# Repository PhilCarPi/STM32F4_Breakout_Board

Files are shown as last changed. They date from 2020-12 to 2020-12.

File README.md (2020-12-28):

# STM32F4_Breakout_Board
4 layer PCB that serves as a breakout board to an STM32F405 chip with an additional IMU chip just for fun. The breakout is for serial ports SPI, USART, I2C, and SWD.

## Front
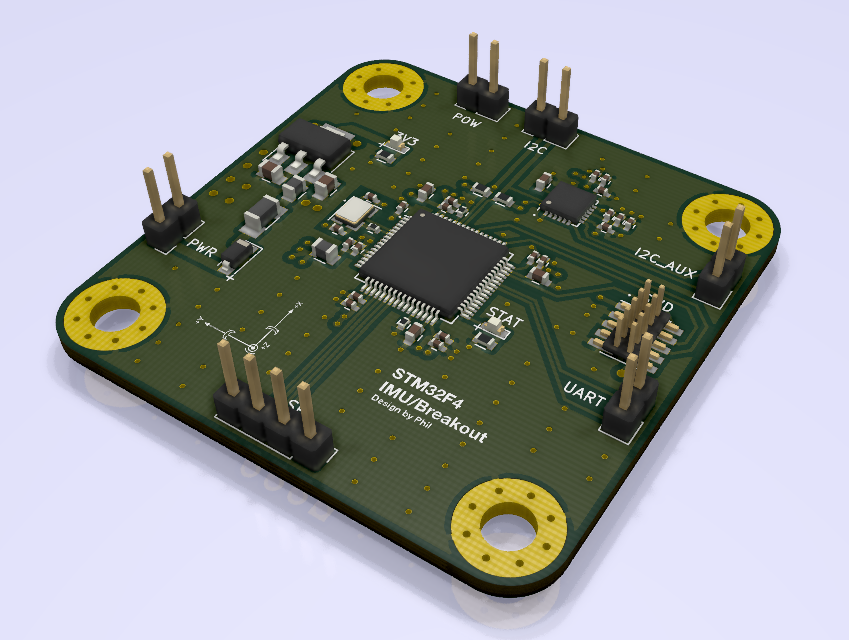
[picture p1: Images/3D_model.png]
3D Model of the board

## Back
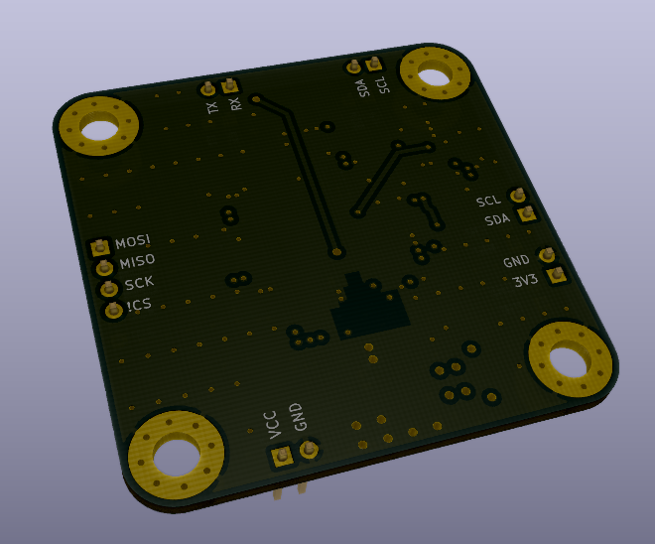
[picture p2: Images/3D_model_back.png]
3D Model of the board


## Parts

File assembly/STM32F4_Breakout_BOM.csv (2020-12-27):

Designator | Quantity | Value | Footprint | LCSC Part #
C1, C2, | 2 | 10uF | 0805 | C15850
C3, | 1 | 10uF | 0603 | C19702
C14, C13, | 2 | 12pF | 0402 | C1547
C15, C4, C5, C6, C7, C8, C9, C10, C11, C12, | 10 | 100nF | 0402 | C1525
C16, | 1 | 10nF | 0402 | C15195
C17, C18, | 2 | 2.2uF | 0603 | C23630
D1, | 1 | B5819W | SOD-123 | C8598
D2, | 1 | Green | 0603 | C72043
D3, | 1 | Blue | 0603 | C72041
F1, | 1 | 500mA | 1206 | C163133
FB1, FB2, | 2 | 100 @ 100Mhz | 0805 | C1015
HSE1, | 1 | 16MHz | SMD-3225_4P | C13738
R2, | 1 | 220 | 0402 | C25091
R5, R6, | 2 | 10k | 0402 | C25744
R7, R1, R4, R3, | 4 | 2k2 | 0603 | C4190
U1, | 1 | AMS1117-3.3 | SOT-223 | C6186
U2, | 1 | STM32F405RGT6 | LQFP-64_10.0x10.0x0.5P | C15742

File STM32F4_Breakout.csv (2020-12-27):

Source: | /Users/phil/Documents/Projects/STM32F4_Breakout_Board/STM32F4_Breakout/STM32F4_Breakout.sch
Date: | Monday, December 21, 2020 at 05:36:26 pm
Tool: | Eeschema (5.0.1-3-g963ef8bb5)
Generator: | /Applications/kicad/kicad.app/Contents/SharedSupport/plugins/bom_csv_grouped_by_value_with_fp.py
Component Count: | 44
Ref | Qnty | Value | Cmp name | Footprint | Description | Vendor
C1, C2, | 2 | 10uF | C_Small | Capacitors_SMD:C_0805 | Unpolarized capacitor, small symbol
C3, | 1 | 10uF | C_Small | Capacitors_SMD:C_0603 | Unpolarized capacitor, small symbol
C14, C13, | 2 | 12pF | C_Small | Capacitors_SMD:C_0402 | Unpolarized capacitor, small symbol
C15, C4, C5, C6, C7, C8, C9, C10, C11, C12, | 10 | 100nF | C_Small | Capacitors_SMD:C_0402 | Unpolarized capacitor, small symbol
C16, | 1 | 10nF | C_Small | Capacitors_SMD:C_0402 | Unpolarized capacitor, small symbol
C17, C18, | 2 | 2.2uF | C_Small | Capacitors_SMD:C_0603 | Unpolarized capacitor, small symbol
D1, | 1 | B5819W | D_Schottky_Small | Diodes_SMD:D_SOD-123 | Schottky diode, small symbol
D2, | 1 | Green | LED_Small | LEDs:LED_0603 | Light emitting diode, small symbol
D3, | 1 | Blue | LED_Small | LEDs:LED_0603 | Light emitting diode, small symbol
F1, | 1 | 500mA | Fuse_Small | Fuse_Holders_and_Fuses:Fuse_SMD1206_Wave | Fuse, small symbol
FB1, FB2, | 2 | 100 @ 100Mhz | Ferrite_Bead_Small | Inductors_SMD:L_0805 | Ferrite bead, small symbol
H1, H2, H3, H4, | 4 | MountingHole_Pad | MountingHole_Pad | Mounting_Holes:MountingHole_4.3mm_M4_Pad_Via | Mounting Hole with connection
HSE1, | 1 | 16MHz | Crystal_GND24_Small | Crystals:Crystal_SMD_3225-4pin_3.2x2.5mm | Four pin crystal, GND on pins 2 and 4, small symbol
J1, J5, J2, J3, | 4 | Conn_01x02 | Conn_01x02 | Pin_Headers:Pin_Header_Straight_1x02_Pitch2.54mm | Generic connector, single row, 01x02, script generated (kicad-library-utils/schlib/autogen/connector/)
J4, | 1 | Conn_02x05_Odd_Even | Conn_02x05_Odd_Even | Pin_Headers:Pin_Header_Straight_2x05_Pitch1.27mm_SMD | Generic connector, double row, 02x05, odd/even pin numbering scheme (row 1 odd numbers, row 2 even numbers), script generated (kicad-library-utils/schlib/autogen/connector/)
J6, | 1 | Conn_01x04 | Conn_01x04 | Pin_Headers:Pin_Header_Straight_1x04_Pitch2.54mm | Generic connector, single row, 01x04, script generated (kicad-library-utils/schlib/autogen/connector/)
R2, | 1 | 220 | R_Small | Resistors_SMD:R_0402 | Resistor, small symbol
R5, R6, | 2 | 10k | R_Small | Resistors_SMD:R_0402 | Resistor, small symbol
R7, R1, R4, R3, | 4 | 2k2 | R_Small | Resistors_SMD:R_0603 | Resistor, small symbol
U1, | 1 | AMS1117-3.3 | AMS1117-3.3 | TO_SOT_Packages_SMD:SOT-223-3_TabPin2 | 1A Low Dropout regulator, positive, 3.3V fixed output, SOT-223
U2, | 1 | STM32F405RGT6 | STM32F405RGTx | Housings_QFP:LQFP-64_10x10mm_Pitch0.5mm | ARM Cortex-M4 MCU, 1024KB flash, 128KB RAM, 168MHz, 1.8-3.6V, 51 GPIO, LQFP-64

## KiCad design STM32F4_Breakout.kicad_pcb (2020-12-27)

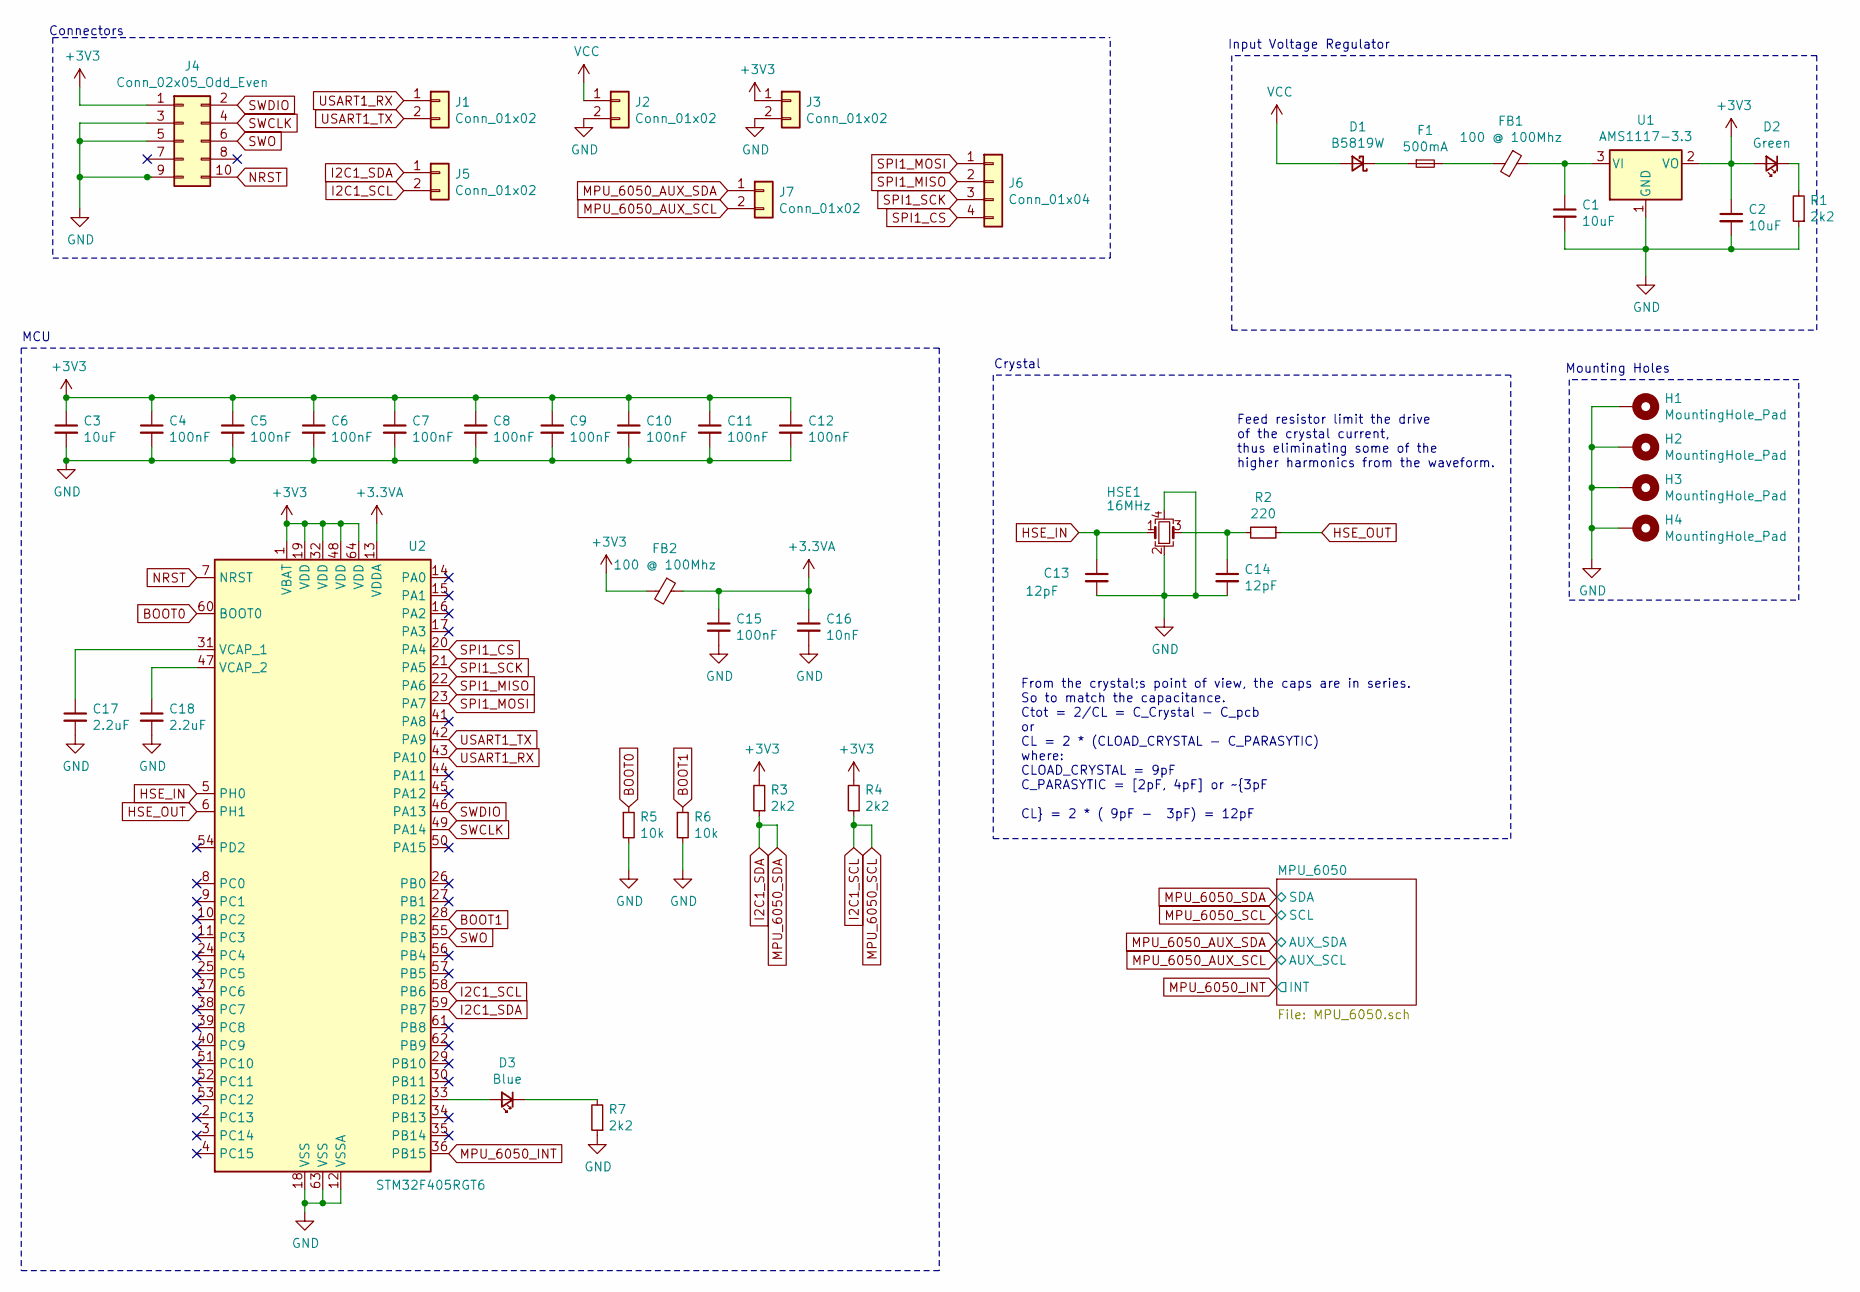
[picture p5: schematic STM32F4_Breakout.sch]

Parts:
C1, C2: 10uF; C_0805
C3: 10uF; C_0603
C4, C5, C6, C7, C8, C9, C10, C11, C12, C15: 100nF; C_0402
C13, C14: 12pF; C_0402
C16: 10nF; C_0402
C17, C18: 2.2uF; C_0603
D1: B5819W; D_SOD-123
D2: Green; LED_0603
D3: Blue; LED_0603
F1: 500mA; Fuse_SMD1206_Wave
FB1, FB2: 100 @ 100Mhz; L_0805
H1, H2, H3, H4: MountingHole_Pad; MountingHole_4.3mm_M4_Pad_Via
HSE1: 16MHz; Crystal_SMD_3225-4pin_3.2x2.5mm
J1, J2, J3, J5, J7: Conn_01x02; Pin_Header_Straight_1x02_Pitch2.54mm
J4: Conn_02x05_Odd_Even; Pin_Header_Straight_2x05_Pitch1.27mm_SMD; MPN 20021121-00010C4LF
J6: Conn_01x04; Pin_Header_Straight_1x04_Pitch2.54mm
R1, R3, R4, R7: 2k2; R_0603
R2: 220; R_0402
R5, R6: 10k; R_0402
U1: AMS1117-3.3; SOT-223-3_TabPin2
U2: STM32F405RGT6; LQFP-64_10x10mm_Pitch0.5mm

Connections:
+3.3VA: C15.1, C16.1, FB2.1, U2.13 (VDDA)
AUX_SCL: J7.1; also elsewhere on the board
AUX_SDA: J7.2; also elsewhere on the board
BOOT0: R5.1, U2.60 (BOOT0)
BOOT1: R6.1, U2.28 (PB2)
GND: C1.2, C2.2, C3.2, C4.2, C5.2, C6.2, C7.2, C8.2, C9.2, C10.2, C11.2, C12.2, C13.2, C14.2, C15.2, C16.2, C17.2, C18.2, H1.1, H2.1, H3.1, H4.1, HSE1.2, HSE1.4, J2.2, J3.2, J4.3, J4.5, J4.9, R1.1, R5.2, R6.2, R7.1, U1.1 (GND), U2.12 (VSSA), U2.18 (VSS), U2.63 (VSS); also elsewhere on the board
HSE_IN: C13.1, HSE1.1, U2.5 (PH0)
HSE_OUT: R2.1, U2.6 (PH1)
I2C1_SCL: J5.2, R4.1, U2.58 (PB6); also elsewhere on the board
I2C1_SDA: J5.1, R3.1, U2.59 (PB7); also elsewhere on the board
INT: U2.52 (PC11); also elsewhere on the board
NRST: J4.10, U2.7 (NRST)
unnamed: C1.1, FB1.1, U1.3 (VI)
unnamed: C14.1, HSE1.3, R2.2
unnamed: C17.1, U2.31 (VCAP_1)
unnamed: C18.1, U2.47 (VCAP_2)
unnamed: D1.1 (K), F1.1
unnamed: D2.1 (K), R1.2
unnamed: D3.1 (K), R7.2
unnamed: D3.2 (A), U2.33 (PB12)
unnamed: F1.2, FB1.2
SPI1_CS: J6.4, U2.20 (PA4)
SPI1_MISO: J6.2, U2.22 (PA6)
SPI1_MOSI: J6.1, U2.23 (PA7)
SPI1_SCK: J6.3, U2.21 (PA5)
SWCLK: J4.4, U2.49 (PA14)
SWDIO: J4.2, U2.46 (PA13)
SWO: J4.6, U2.55 (PB3)
USART1_RX: J1.1, U2.43 (PA10)
USART1_TX: J1.2, U2.42 (PA9)
VCC: D1.2 (A), J2.1

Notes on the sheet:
Input Voltage Regulator
From the crystal;s point of view, the caps are in series. So to match the capacitance. Ctot = 2/CL = C_Crystal - C_pcb or CL = 2 * (CLOAD_CRYSTAL - C_PARASYTIC) where: CLOAD_CRYSTAL = 9pF C_PARASYTIC = [2pF, 4pF] or ~3pF CL = 2 * ( 9pF - 3pF) = 12pF
Feed resistor limit the drive of the crystal current, thus eliminating some of the higher harmonics from the waveform.
Crystal
MCU
Connectors
Mounting Holes

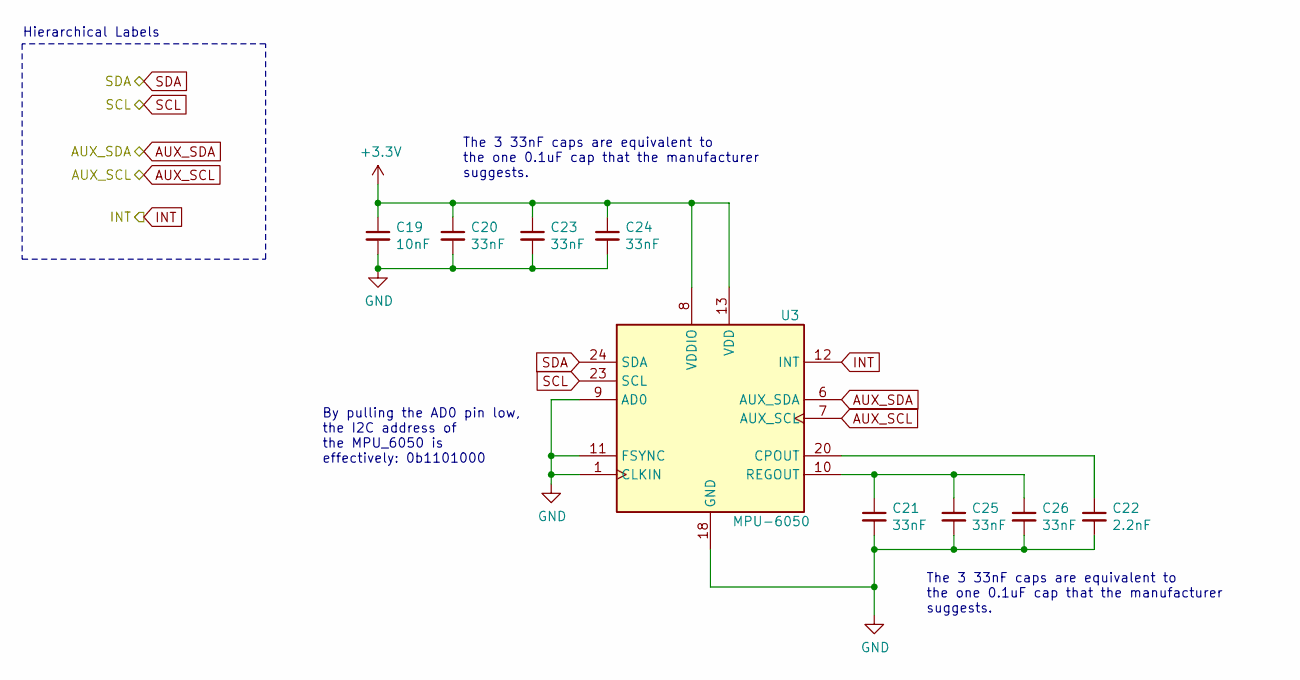
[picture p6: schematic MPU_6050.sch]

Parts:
C19: 10nF; C_0402
C20, C21, C23, C24, C25, C26: 33nF; C_0402
C22: 2.2nF; C_0603
U3: MPU-6050; QFN-24_4x4mm_Pitch0.5mm

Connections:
AUX_SCL: U3.7 (AUX_SCL); also elsewhere on the board
AUX_SDA: U3.6 (AUX_SDA); also elsewhere on the board
GND: C19.2, C20.2, C21.2, C22.2, C23.2, C24.2, C25.2, C26.2, U3.1 (CLKIN), U3.9 (AD0), U3.11 (FSYNC), U3.18 (GND); also elsewhere on the board
I2C1_SCL: U3.23 (SCL); also elsewhere on the board
I2C1_SDA: U3.24 (SDA); also elsewhere on the board
INT: U3.12 (INT); also elsewhere on the board
unnamed: C21.1, C25.1, C26.1, U3.10 (REGOUT)
unnamed: C22.1, U3.20 (CPOUT)

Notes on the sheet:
Hierarchical Labels
By pulling the AD0 pin low, the I2C address of the MPU_6050 is effectively: 0b1101000
The 3 33nF caps are equivalent to the one 0.1uF cap that the manufacturer suggests.

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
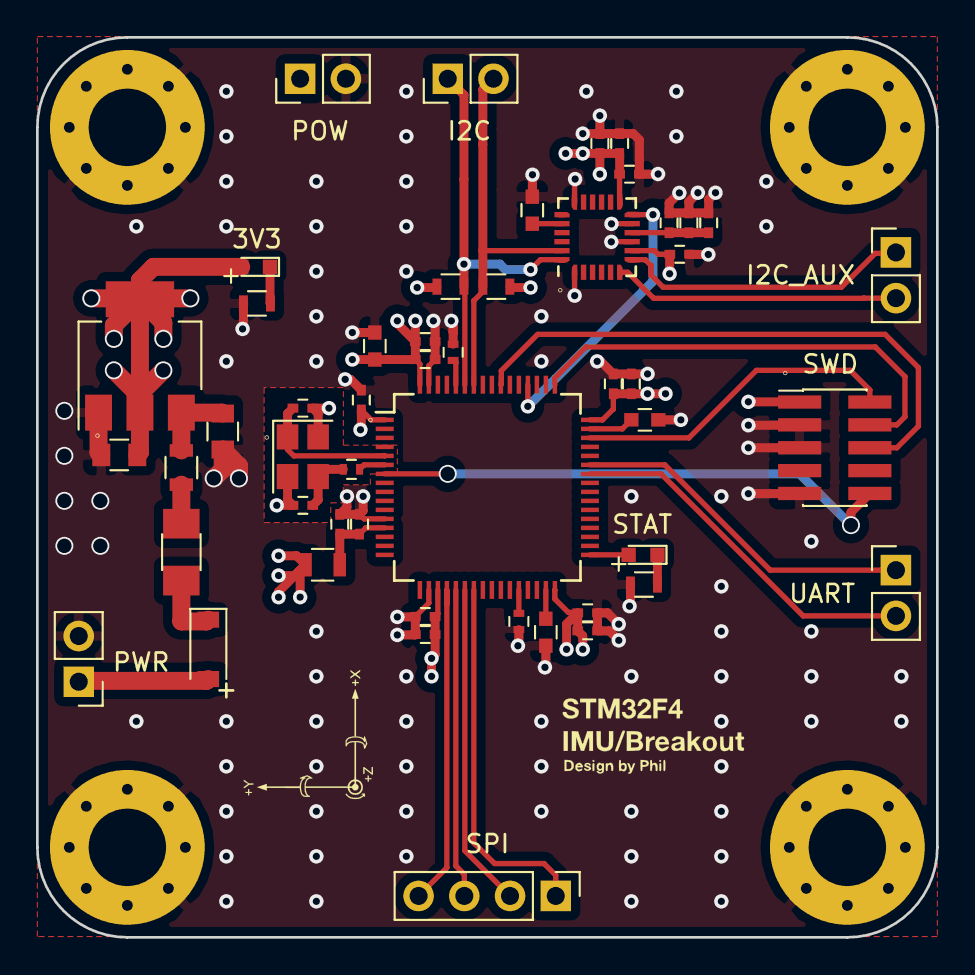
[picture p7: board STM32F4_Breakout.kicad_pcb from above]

Board: 4 copper layers, 50.0 x 50.0 mm, 54 parts (0 on the bottom side), 34 nets.

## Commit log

2020-12-27 Moved local files to remote repository.
    [MPU_6050.sch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]
2020-12-27 Added 3D model image of the board.
